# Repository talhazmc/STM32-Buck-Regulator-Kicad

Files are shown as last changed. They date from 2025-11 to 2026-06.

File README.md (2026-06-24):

# STM32F4 Test Board with Buck Regulator

This repository contains my KiCad PCB design project for an STM32F4-based test and development board with an integrated buck regulator power section.

The board was designed as a compact embedded systems development platform that includes an STM32F4 microcontroller, programming/debugging interfaces, communication headers, status indicators, and onboard power regulation.

---

## Project Overview

The main purpose of this project was to design a custom STM32F4 test board using KiCad.

The board includes the essential hardware required for working with an STM32F4 microcontroller, such as power input, voltage regulation, SWD programming interface, UART and I2C headers, boot/run control, USB connection, and status LEDs.

This project combines embedded system PCB design and power supply design on a single board.

---

## 3D PCB View

The 3D view shows the physical placement of the STM32F4 microcontroller, SWD header, UART and I2C connectors, USB section, power input terminal, buck regulator components, status LEDs, and mounting holes.

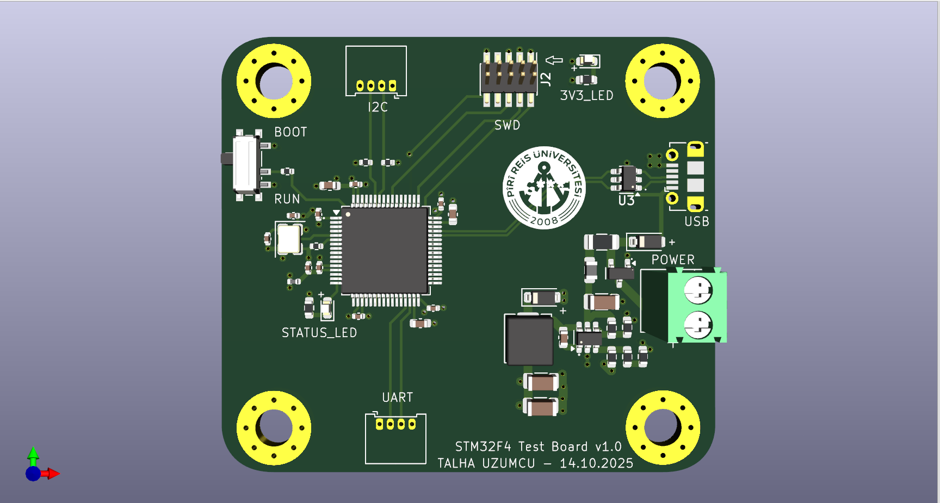
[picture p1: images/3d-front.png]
3D PCB View


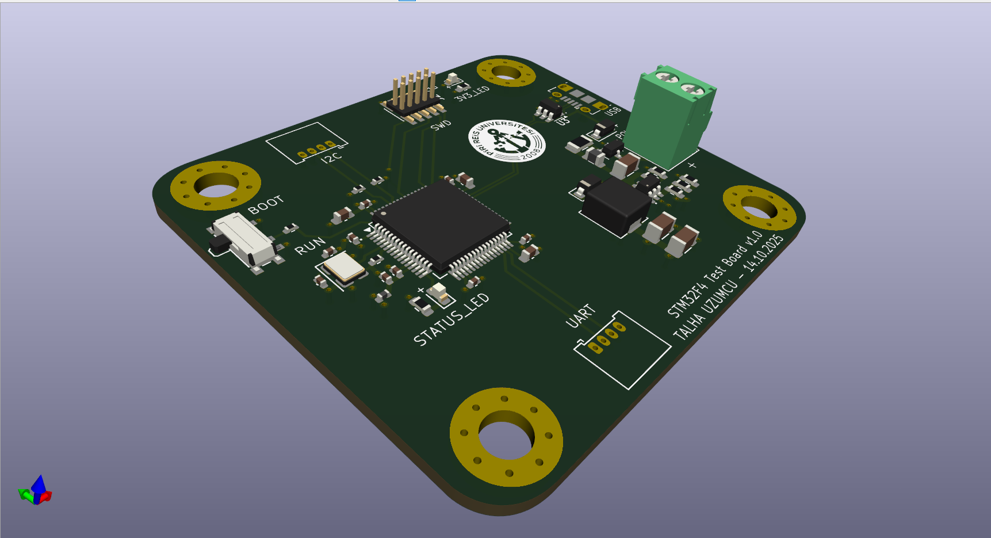
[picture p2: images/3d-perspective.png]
3D Perspective View


---

## PCB Layout

The PCB layout was created in KiCad.

The STM32F4 microcontroller was placed near the center of the board. Communication and programming headers were positioned around the MCU for easier access. The power regulation section was placed on the right side of the board, close to the power input terminal.

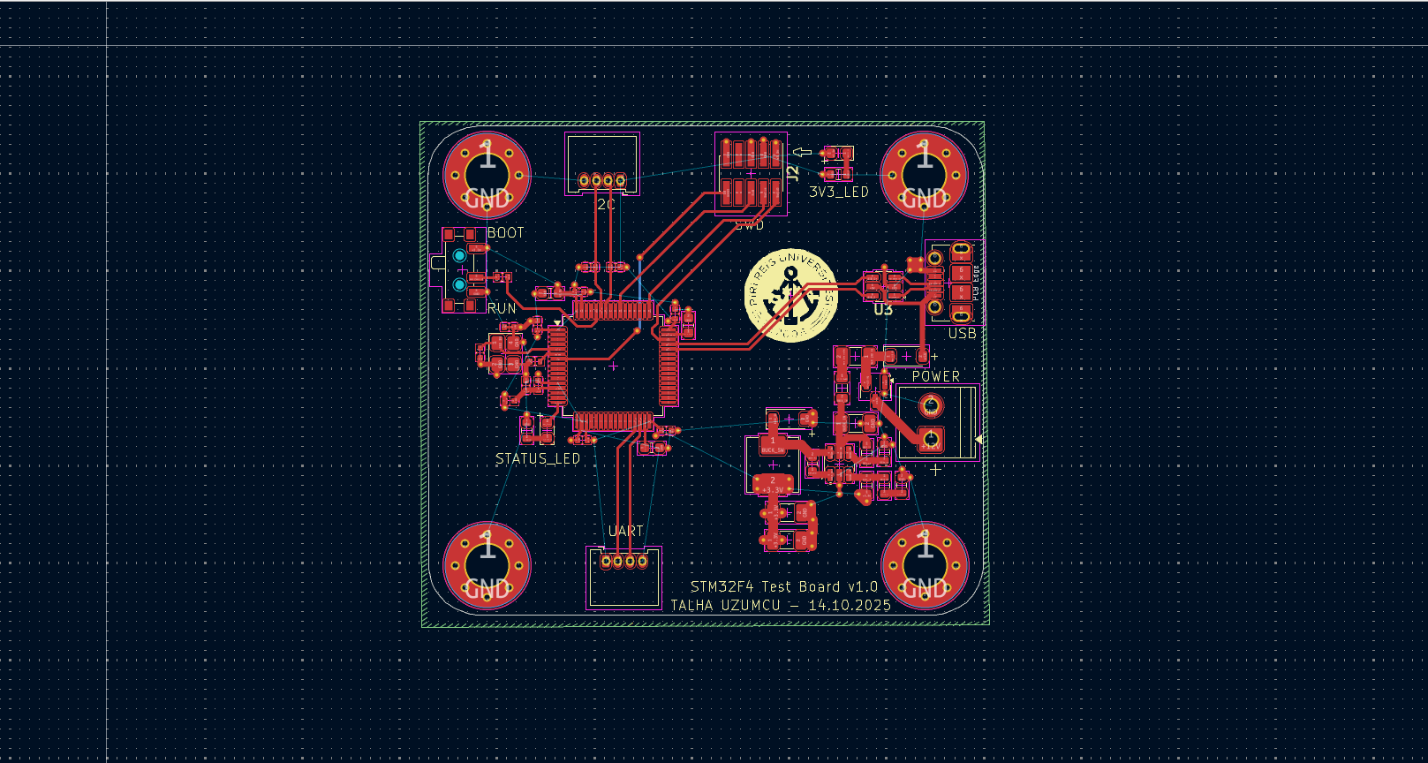
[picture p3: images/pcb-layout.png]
PCB Layout


---

## Main Features

- STM32F4 microcontroller-based custom test board
- Integrated buck regulator power section
- SWD programming/debugging connector
- UART communication header
- I2C communication header
- USB connection section
- BOOT and RUN control
- Status LED
- 3.3V power indicator LED
- External power input terminal
- Mounting holes for mechanical fixing

---

## Main Components

- STM32F4 microcontroller
- Buck regulator components
- Inductor
- Power input terminal block
- USB connector section
- SWD header
- UART header
- I2C header
- BOOT switch
- RUN switch
- Status LEDs
- Resistors and capacitors
- Mounting holes

---

## Working Principle

The board is designed around an STM32F4 microcontroller.

The external DC input is connected through the power terminal. The onboard buck regulator section converts the input voltage to the required lower voltage level for the system.

The SWD connector allows the STM32F4 microcontroller to be programmed and debugged. UART and I2C headers provide communication interfaces for external modules, sensors, or other embedded systems.

The BOOT and RUN controls are used during programming, reset, and startup operations. Status LEDs provide visual feedback about the board state and power status.

---

## PCB Design Notes

- The STM32F4 MCU was placed centrally for organized signal routing.
- SWD, UART, and I2C headers were placed near the board edges for easy access.
- The buck regulator section was separated from the microcontroller area.
- Wider traces were used in the power section.
- Mounting holes were added for mechanical stability.
- The board was checked using KiCad 3D Viewer.

---

## What I Learned

Through this project, I gained practical experience in:

- Designing STM32-based embedded system PCBs
- Using KiCad for schematic, PCB layout, and 3D visualization
- Integrating MCU, power, programming, and communication sections
- Designing a buck regulator power stage on the same PCB
- Routing microcontroller signals
- Planning PCB layout for debugging and testing
- Creating a more professional embedded development board structure

---

## Tools and Technologies

- KiCad
- STM32F4
- Buck regulator
- Embedded systems
- PCB design
- SWD programming
- UART communication
- I2C communication
- Power electronics

---

## Author

**Talha Üzümcü**  
Electrical and Electronics Engineer  
GitHub: [talhazmc](https://github.com/talhazmc)

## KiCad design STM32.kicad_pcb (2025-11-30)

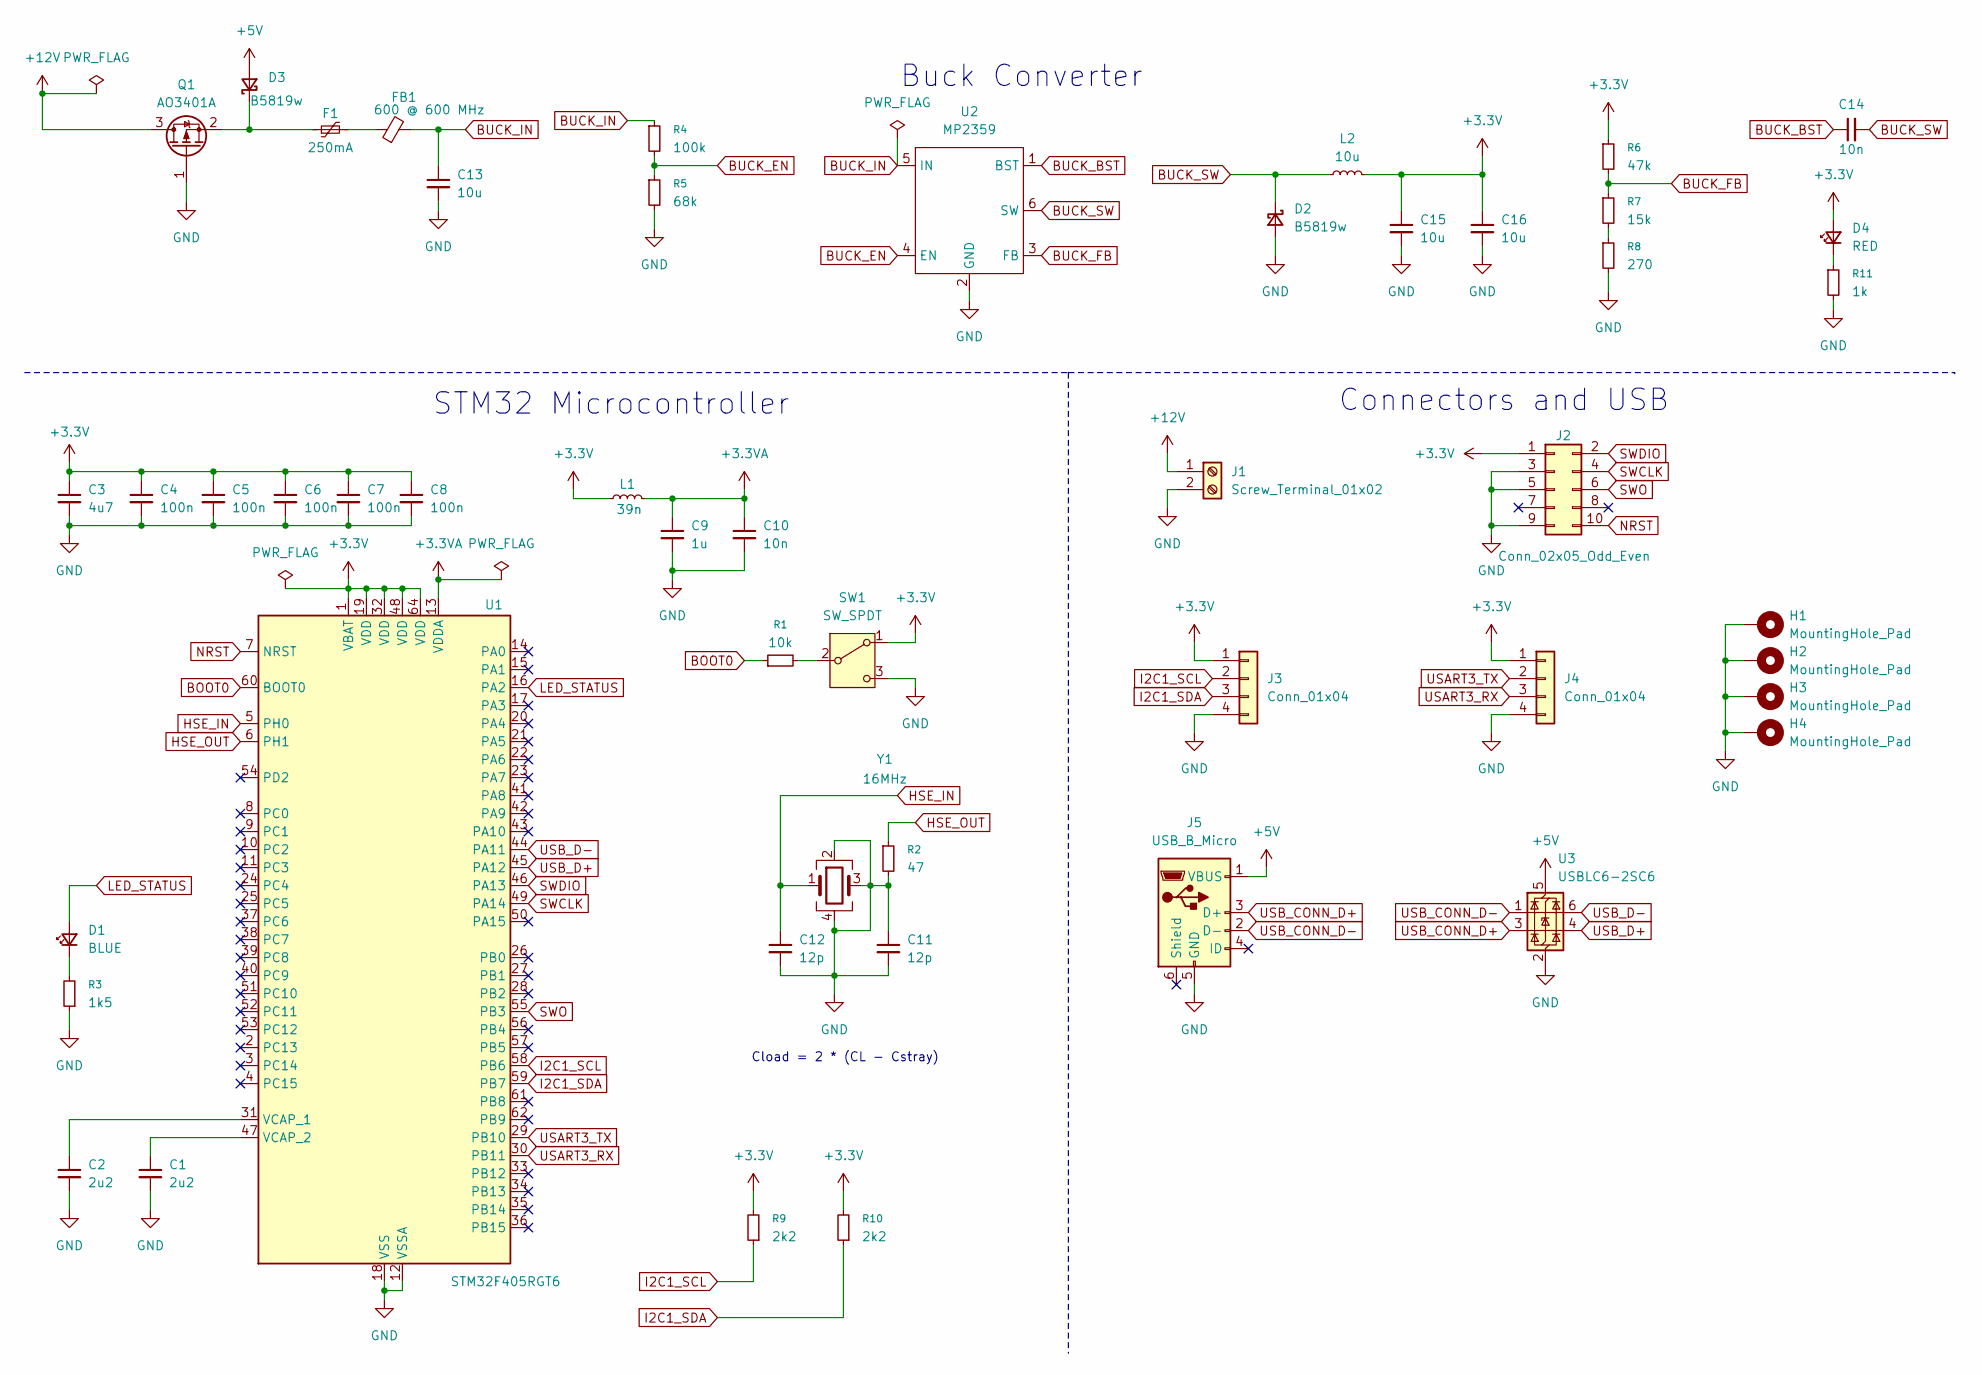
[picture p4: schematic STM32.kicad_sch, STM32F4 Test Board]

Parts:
C1, C2: 2u2; C_0603_1608Metric
C3: 4u7; C_0603_1608Metric
C4, C5, C6, C7, C8: 100n; C_0402_1005Metric
C9: 1u; C_0402_1005Metric
C10: 10n; C_0402_1005Metric
C11, C12: 12p; C_0402_1005Metric
C13, C15, C16: 10u; C_1206_3216Metric
C14: 10n; C_0603_1608Metric
D1: BLUE; LED_0603_1608Metric
D2, D3: B5819w; D_SOD-123
D4: RED; LED_0603_1608Metric
F1: 250mA; Fuse_1206_3216Metric
FB1: 600 @ 600 MHz; L_0805_2012Metric
H1, H2, H3, H4: MountingHole_Pad; MountingHole_4.3mm_M4_Pad_Via
J1: Screw_Terminal_01x02; TerminalBlock_Phoenix_PT-1,5-2-3.5-H_1x02_P3.50mm_Horizontal
J2: Conn_02x05_Odd_Even; PinHeader_2x05_P1.27mm_Vertical_SMD
J3, J4: Conn_01x04; Molex_PicoBlade_53048-0410_1x04_P1.25mm_Horizontal
J5: USB_B_Micro; USB_Micro-B_Molex-105017-0001
L1: 39n; L_0402_1005Metric
L2: 10u; L_Sunlord_MWSA0503S
Q1: AO3401A; SOT-23
R1: 10k; R_0402_1005Metric
R2: 47; R_0402_1005Metric
R3: 1k5; R_0603_1608Metric
R4: 100k; R_0603_1608Metric
R5: 68k; R_0603_1608Metric
R6: 47k; R_0603_1608Metric
R7: 15k; R_0603_1608Metric
R8: 270; R_0603_1608Metric
R9, R10: 2k2; R_0402_1005Metric
R11: 1k; R_0603_1608Metric
SW1: SW_SPDT; SW_SPDT_PCM12
U1: STM32F405RGT6; LQFP-64_10x10mm_P0.5mm
U2: MP2359; SOT-23-6
U3: USBLC6-2SC6; SOT-23-6
Y1: 16MHz; Crystal_SMD_3225-4Pin_3.2x2.5mm

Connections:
+3.3V: C3.1, C4.1, C5.1, C6.1, C7.1, C8.1, C15.1, C16.1, D4.2 (A), J2.1, J3.1, J4.1, L1.1, L2.2, R6.1, R9.2, R10.2, SW1.1 (A), U1.1 (VBAT), U1.19 (VDD), U1.32 (VDD), U1.48 (VDD), U1.64 (VDD)
+3.3VA: C9.1, C10.1, L1.2, U1.13 (VDDA)
+5V: D3.2 (A), J5.1 (VBUS), U3.5 (VBUS)
+12V: J1.1, Q1.3 (D)
BOOT0: R1.1, U1.60 (BOOT0)
BUCK_BST: C14.1, U2.1 (BST)
BUCK_EN: R4.2, R5.1, U2.4 (EN)
BUCK_FB: R6.2, R7.1, U2.3 (FB)
BUCK_IN: C13.1, FB1.2, R4.1, U2.5 (IN)
BUCK_SW: C14.2, D2.1 (K), L2.1, U2.6 (SW)
GND: C1.2, C2.2, C3.2, C4.2, C5.2, C6.2, C7.2, C8.2, C9.2, C10.2, C11.1, C11.2, C12.2, C13.2, C15.2, C16.2, D2.2 (A), H1.1, H2.1, H3.1, H4.1, J1.2, J2.3, J2.5, J2.9, J3.4, J4.4, J5.5 (GND), Q1.1 (G), R2.2, R3.1, R5.2, R8.2, R11.2, SW1.3 (C), U1.12 (VSSA), U1.18 (VSS), U1.63 (VSS), U2.2 (GND), U3.2 (GND), Y1.2, Y1.3, Y1.4
HSE_IN: C12.1, U1.5 (PH0), Y1.1
HSE_OUT: R2.1, U1.6 (PH1)
I2C1_SCL: J3.2, R9.1, U1.58 (PB6)
I2C1_SDA: J3.3, R10.1, U1.59 (PB7)
LED_STATUS: D1.2 (A), U1.16 (PA2)
NRST: J2.10, U1.7 (NRST)
unnamed: D1.1 (K), R3.2
unnamed: D3.1 (K), F1.1, Q1.2 (S)
unnamed: D4.1 (K), R11.1
unnamed: F1.2, FB1.1
unnamed: R7.2, R8.1
unnamed: R1.2, SW1.2 (B)
unnamed: C2.1, U1.31 (VCAP_1)
unnamed: C1.1, U1.47 (VCAP_2)
SWCLK: J2.4, U1.49 (PA14)
SWDIO: J2.2, U1.46 (PA13)
SWO: J2.6, U1.55 (PB3)
USART3_RX: J4.3, U1.30 (PB11)
USART3_TX: J4.2, U1.29 (PB10)
USB_CONN_D+: J5.3 (D+), U3.3 (I/O2)
USB_CONN_D-: J5.2 (D-)
USB_CONN_D-: U3.1 (I/O1)
USB_D+: U1.45 (PA12), U3.4 (I/O2)
USB_D-: U1.44 (PA11), U3.6 (I/O1)

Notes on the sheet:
Buck Converter
STM32 Microcontroller
Connectors and USB
Cload = 2 * (CL - Cstray)

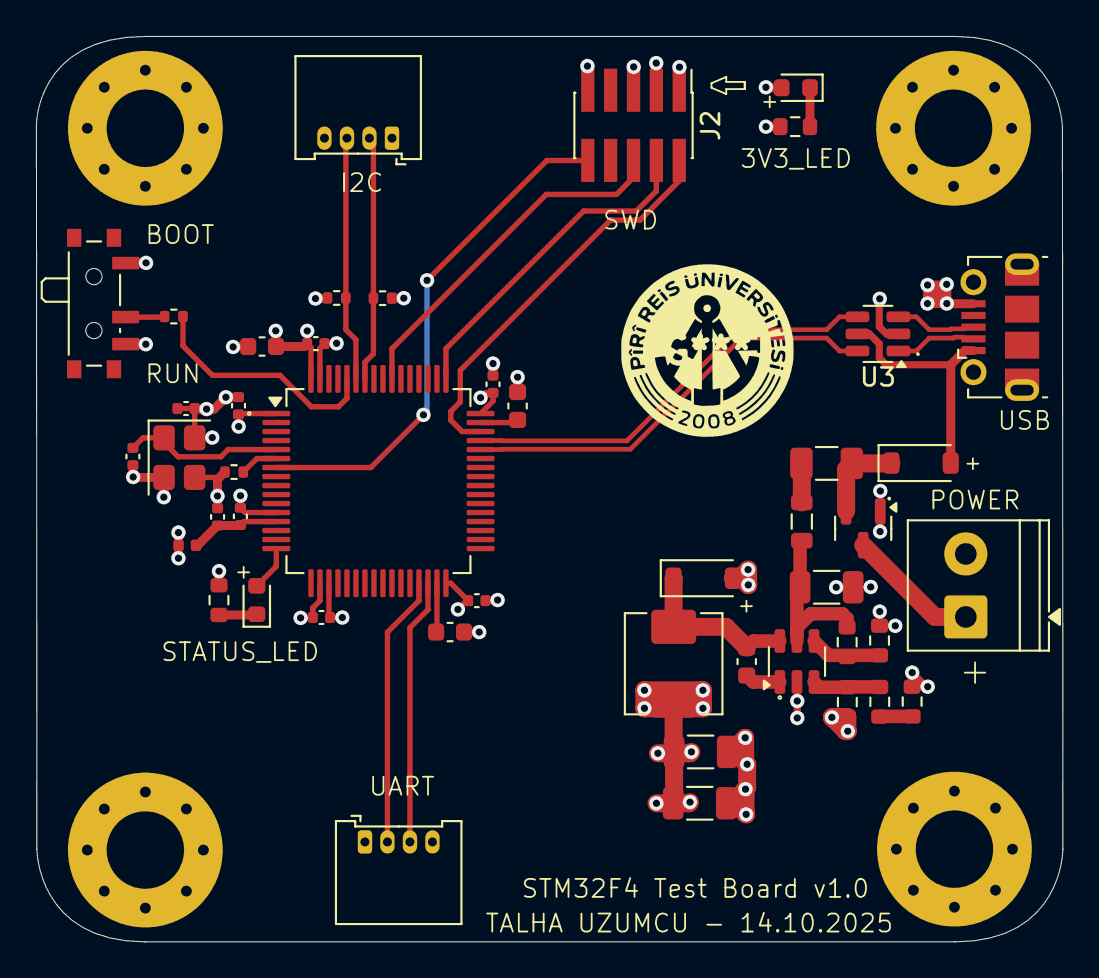
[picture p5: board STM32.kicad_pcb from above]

Board: 4 copper layers, 57.0 x 50.3 mm, 50 parts (0 on the bottom side), 33 nets.
